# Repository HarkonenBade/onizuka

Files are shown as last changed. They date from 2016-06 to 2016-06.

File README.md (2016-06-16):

# onizuka
An FTDI based programming master board. With various daughter boards for programming specific modules.

## Current Daughter Boards
* ESP8266 (ESP-01, ESP-02, ESP-12E)

## License
Onizuka is licensed under [Creative Commons Attribution-ShareAlike 4.0 International (CC BY-SA 4.0)](http://creativecommons.org/licenses/by-sa/4.0/).

Psyduck (used in image on the ESP8266 board, due to the pun on ESP->ESP->Psychic) is Trademark & © of Nintendo 1996-2015

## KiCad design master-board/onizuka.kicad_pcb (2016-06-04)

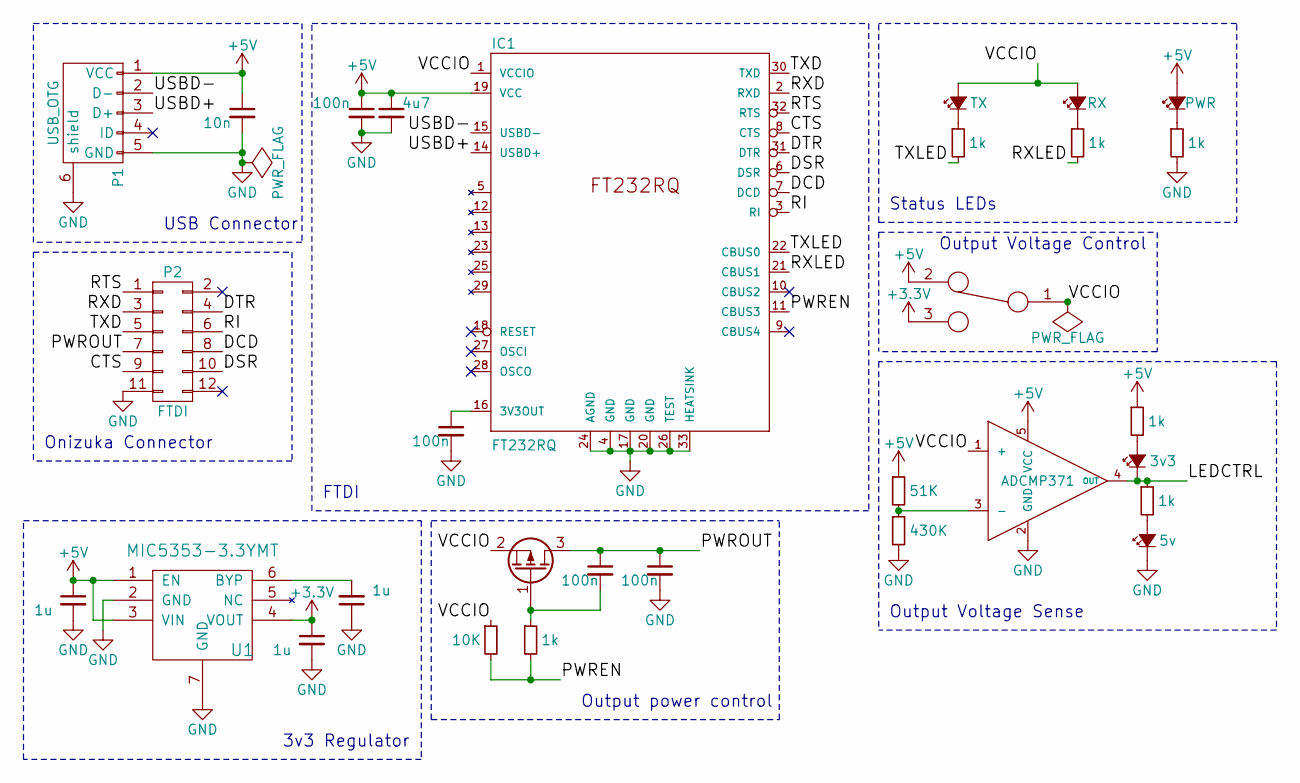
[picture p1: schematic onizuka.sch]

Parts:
C1, C4, C5, C6: 100n; C_0402; Farnell 2524677
C2: 10n; C_0402; Farnell 2524674
C3: 4u7; C_0402; Farnell 2426952
C7, C8, C9: 1u; C_0402; Farnell 2496813
D1: TX; LED_0603; Farnell 2290329
D2: RX; LED_0603; Farnell 8554609
D3: PWR; LED_0603; Farnell 8554609
D4: 3v3; LED_0603; Farnell 2290330
D5: 5v; LED_0603; Farnell 2290329
IC1: FT232RQ; FTDI-FT232RQ-QFN-32; Farnell 1146033
IC2: ADCMP371; SC-70-5; Farnell 2376801
P1: USB_OTG; USB_Micro-B; Farnell 2506104
P2: FTDI; Socket_Strip_Angled_2x06; Farnell 1668355
Q1: Q_PMOS_GSD; SOT-23; Farnell 1894738
R1, R2, R3, R4, R7, R8: 1k; R_0402; Farnell 1358043
R5: 51K; R_0402; Farnell 1358088
R6: 430K; R_0402; Farnell 1358113
R9: 10K; R_0402; Farnell 1358069
SW1: SPDT; 450301014042; Farnell 2134452
U1: MIC5353-3.3YMT; Thin_MLF_6_1.6mm_0.5mm_pitch; Farnell 2510347

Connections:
+3V3: C8.1, SW1.3, U1.4 (VOUT)
+5V: C2.1, C3.1, C4.1, C7.1, D3.2 (A), IC1.19 (VCC), IC2.5 (VCC), P1.1 (VCC), R5.1, R7.1, SW1.2, U1.1 (EN), U1.3 (VIN)
/CTS: IC1.8 (CTS), P2.9
/DCD: IC1.7 (DCD), P2.8
/DSR: IC1.6 (DSR), P2.10
/DTR: IC1.31 (DTR), P2.4
/LEDCTRL: D4.1 (K), IC2.4 (OUT), R8.1
/PWREN: IC1.11 (CBUS3), R4.2, R9.2
/PWROUT: C5.1, C6.1, P2.7, Q1.3 (D)
/RI: IC1.3 (RI), P2.6
/RTS: IC1.32 (RTS), P2.1
/RXD: IC1.2 (RXD), P2.3
/RXLED: IC1.21 (CBUS1), R2.2
/TXD: IC1.30 (TXD), P2.5
/TXLED: IC1.22 (CBUS0), R1.2
/USBD+: IC1.14 (USBD+), P1.3 (D+)
/USBD-: IC1.15 (USBD-), P1.2 (D-)
/VCCIO: D1.2 (A), D2.2 (A), IC1.1 (VCCIO), IC2.1 (+), Q1.2 (S), R9.1, SW1.1
GND: C1.2, C2.2, C3.2, C4.2, C6.2, C7.2, C8.2, C9.1, D5.1 (K), IC1.4 (GND), IC1.17 (GND), IC1.20 (GND), IC1.24 (AGND), IC1.26 (TEST), IC1.33 (HEATSINK), IC2.2 (GND), P1.5 (GND), P1.6 (shield), P2.11, R3.2, R6.2, U1.2 (GND), U1.7 (GND)
unnamed: C1.1, IC1.16 (3V3OUT)
unnamed: C5.2, Q1.1 (G), R4.1
unnamed: C9.2, U1.6 (BYP)
unnamed: D1.1 (K), R1.1
unnamed: D2.1 (K), R2.1
unnamed: D3.1 (K), R3.1
unnamed: D4.2 (A), R7.2
unnamed: D5.2 (A), R8.2
unnamed: IC2.3 (-), R5.2, R6.1

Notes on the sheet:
USB Connector
FTDI
3v3 Regulator
Output power control
Output Voltage Control
Onizuka Connector
Status LEDs
Output Voltage Sense

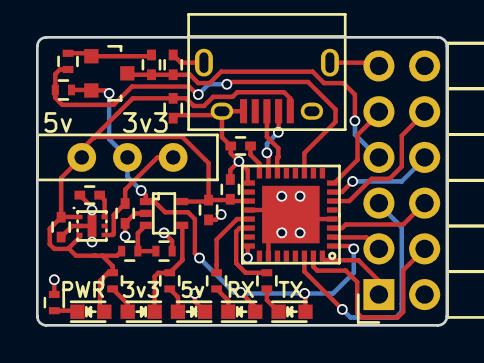
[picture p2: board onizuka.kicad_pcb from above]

Board: 2 copper layers, 22.8 x 16.0 mm, 30 parts (0 on the bottom side), 28 nets.

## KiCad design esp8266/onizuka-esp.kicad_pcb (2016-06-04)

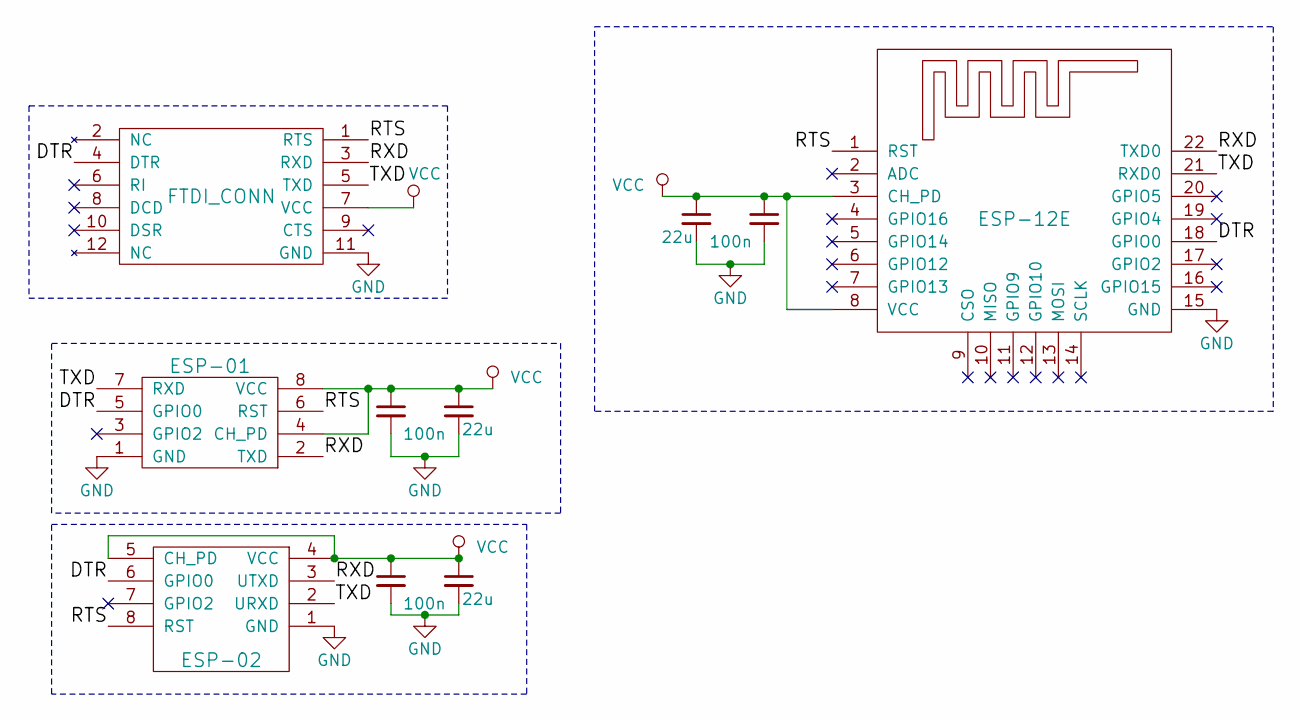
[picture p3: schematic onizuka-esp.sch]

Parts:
C1, C4, C6: 100n; C_0603; Farnell 2524817
C2, C3, C7: 22u; C_0603; Farnell 2494232
P1: FTDI_CONN; Pin_Header_Angled_2x06; Farnell 1593452
U1: ESP-01; Farnell 1593489
U2: ESP-12E; ESP-12E-Program
U3: ESP-02; ESP-02-Program

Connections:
/DTR: P1.4 (DTR), U1.5 (GPIO0), U2.18 (GPIO0), U3.6 (GPIO0)
/RTS: P1.1 (RTS), U1.6 (RST), U2.1 (RST), U3.8 (RST)
/RXD: P1.3 (RXD), U1.2 (TXD), U2.22 (TXD0), U3.3 (UTXD)
/TXD: P1.5 (TXD), U1.7 (RXD), U2.21 (RXD0), U3.2 (URXD)
GND: C1.2, C2.2, C3.2, C4.2, C6.2, C7.2, P1.11 (GND), U1.1 (GND), U2.15 (GND), U3.1 (GND)
VCC: C1.1, C2.1, C3.1, C4.1, C6.1, C7.1, P1.7 (VCC), U1.4 (CH_PD), U1.8 (VCC), U2.3 (CH_PD), U2.8 (VCC), U3.4 (VCC), U3.5 (CH_PD)

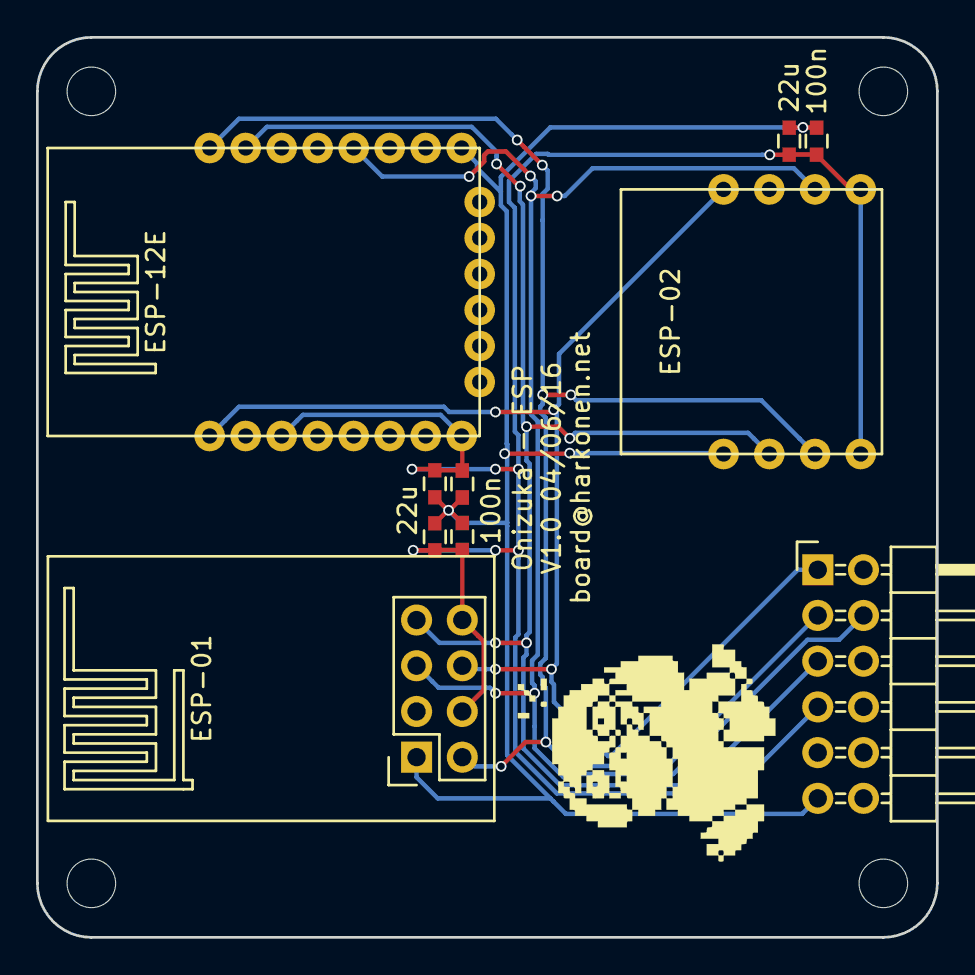
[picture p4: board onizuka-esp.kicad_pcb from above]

Board: 2 copper layers, 50.0 x 50.0 mm, 10 parts (0 on the bottom side), 6 nets.

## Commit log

2016-05-21 more shenanigans
    [onizuka.kicad_pcb, onizuka.sch]
2016-05-23 ESP8266 daughter board
    [onizuka-esp.kicad_pcb, onizuka-esp.sch, onizuka.kicad_pcb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]
2016-05-23 Delete AMPHENOL FCI 10103592-0001LF.kicad_mod
    Fix bugged filename.
2016-05-24 Slight schematic rework, much PCB faffing
    [onizuka.kicad_pcb, onizuka.sch]
2016-05-25 Various upgrades, also ESP-12E footprint for ESP board
    [onizuka-esp.kicad_pcb, onizuka-esp.sch, onizuka.kicad_pcb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]
2016-05-30 More faffing
    [onizuka-esp.kicad_pcb, onizuka.kicad_pcb]
2016-05-31 Board reshuffle, new regulator
    [onizuka.kicad_pcb, onizuka.sch]
2016-05-31 3d model path correction
    [onizuka-esp.kicad_pcb]
2016-05-31 Faffing, added connections to heatsink pad on FTDI, moved connector in slightly.
    [onizuka.kicad_pcb, onizuka.sch]
2016-05-31 Tidied up schema, started to add farnell codes for components.
    [onizuka.kicad_pcb, onizuka.sch]
2016-06-01 Shift to independant kicad lib repo
2016-06-01 Various tweaks
    [onizuka-esp.kicad_pcb, onizuka-esp.sch, onizuka.kicad_pcb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]
2016-06-01 Add board names revisions and emails.
    [onizuka-esp.kicad_pcb, onizuka.kicad_pcb]
2016-06-01 Updated switch
    [onizuka.kicad_pcb, onizuka.sch]
2016-06-01 Poked around, fixed minor bug, tweaked silk slightly.
    [onizuka.kicad_pcb, onizuka.sch]
2016-06-02 Many faffing, new ESP stuff.
    [onizuka-esp.kicad_pcb, onizuka-esp.sch, onizuka.kicad_pcb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]
2016-06-03 Various shuffling, adding farnell part numbers.
    [onizuka-esp.kicad_pcb, onizuka-esp.sch, onizuka.kicad_pcb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]
2016-06-03 Centre pin header
    [onizuka-esp.kicad_pcb]
2016-06-03 Rounded PCB corners
    [onizuka-esp.kicad_pcb, onizuka.kicad_pcb]
2016-06-03 ESP board rearrainge, also logo.
    [onizuka-esp.kicad_pcb]
2016-06-04 Final tweaks, more farnell part numbers, BOM, gerbers
    [onizuka-B.Cu.gbl, onizuka-B.Mask.gbs, onizuka-B.Paste.gbp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]
2016-06-04 Updated Thin MLF footprint, regenned gerbers
    [onizuka-B.Cu.gbl, onizuka-B.Mask.gbs, onizuka-B.Paste.gbp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]
